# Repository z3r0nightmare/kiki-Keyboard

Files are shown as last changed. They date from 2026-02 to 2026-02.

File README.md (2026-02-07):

# Kiki v1 ⌨️

Kiki v1 is a modernized, high-performance split mechanical keyboard. This design is inspired by the **Corne v4.1 (Cherry Version)** but optimized for the **RP2040** processor. It features integrated MCU support, dual rotary encoders per side, and native **Vial** compatibility for real-time configuration.

---

## 📂 Repository Contents
* **/Hardware**: Gerber files, PCB designs, and BOM (Bill of Materials). Optimized for **NextPCB** assembly.
* **/Firmware**: Compiled `.uf2` files and QMK/Vial source code.
* **/Case**: STL files for 3D printing and CAD models for custom enclosures.

---

## 🛠 Hardware Build & Assembly
This PCB integrates the Raspberry Pi RP2040 directly onto the board, eliminating the need for separate Pro Micro controllers.

### 1. PCB Manufacturing
The files in the `/Hardware` folder are optimized for the **NextPCB** workflow. By using their assembly service with the provided **BOM** and **CPL** files, you can receive your boards with all SMD components (MCU, diodes, resistors) pre-soldered.

### 2. Rotary Encoders
The Kiki v1 supports dual encoders per side for maximum control. Note that firmware updates are ongoing to further optimize pin assignments; always ensure you are flashing the latest `.uf2` from the `/Firmware` folder to keep your hardware features fully active.

---

## 🚀 Software & Customization

### 1. Vial Support (Real-time Edits)
The Kiki v1 is **Vial-ready**, allowing you to change your layout, RGB effects, and encoder behavior without ever touching a line of code.
* **Download**: [vial.today](https://get.vial.today/)
* **Usage**: Plug in your keyboard, open the Vial app, and start remapping.
* **Reset**: If the layout visuals appear incorrectly in the app, navigate to `Security -> Reset to Factory Defaults` in the Vial menu to refresh the coordinate map.

### 2. Layout Options
The firmware supports multiple physical configurations:
* **3x6_3**: Standard 6-column experience.
* **3x5_3**: Compact 5-column layout for minimal finger travel.

### 3. OLED & Bongo Cat
The integrated OLED displays feature a reactive **Bongo Cat** animation. The cat's typing speed scales with your WPM (Words Per Minute), and the screen also displays your current layer and last key pressed.

---

## ⚡ How to Flash
1. Hold the **BOOT** button on the PCB while plugging in the USB-C cable.
2. A drive named `RPI-RP2` will appear on your computer.
3. Drag and drop the provided `.uf2` file onto that drive.
4. The keyboard will automatically reboot and be ready to use.

---

## 🎨 Credits & Inspiration
* **Base Inspiration**: Inspired by the **Corne (Crkbd) v4.1 Cherry** by foostan.
* **Firmware Framework**: Powered by [QMK Firmware](https://qmk.fm/) and [Vial](https://get.vial.today/).
* **Optimizations**: Custom RP2040 pinout integration and dual-encoder support.

---

## 📜 License
Open-source for personal use. If you build a Kiki v1 or feature it in a project, please link back to this repository!

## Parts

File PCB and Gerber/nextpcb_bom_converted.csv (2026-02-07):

Designator | Qty | Manufacturer | MPN | Package | Description
Y1,rY1 | 2 | EPSON | Q22FA23V00418 | SMD3225-4P | 12MHz Crystal 18pF
C1,C2,rC1,rC2 | 4 | FH | 0402CG270J500NT | 0402 | 27pF C0G 0402 Capacitor
R4,R5,rR4,rR5 | 4 | FOJAN | FRC0402F27R0TS | 0402 | 27Ω 0402 Resistor (or similar)
EXSW1,EXSW2,SW1,SW10,SW11,SW12,SW13,SW14,SW15,SW16,SW17,SW18,SW19,SW2,SW20,SW21,SW3,SW4,SW5,SW6,SW7,SW8,SW9,rEXSW1,rEXSW2,rSW1,rSW10,rSW11,rSW12,rSW13,rSW14,rSW15,rSW16,rSW17,rSW18,rSW19,rSW2,rSW20,rSW21,rSW3,rSW4,rSW5,rSW6,rSW7,rSW8,rSW9 | 46 | Kailh | CPG151101S11-16 | Pushbutton | Kailh Pushbutton Switch
J2,rJ2 | 2 | Korean Hroparts Elec | PJ-399B-6A | Through Hole | 3.5mm Headphone Jack
J1,rJ1 | 2 | Korean Hroparts Elec | TYPE-C-31-M-13C | SMD | USB Type-C Connector 16POS
EXLED1,EXLED2,LED1,LED10,LED11,LED12,LED13,LED14,LED15,LED16,LED17,LED18,LED19,LED2,LED20,LED21,LED3,LED4,LED5,LED6,LED7,LED8,LED9,rEXLED1,rEXLED2,rLED1,rLED10,rLED11,rLED12,rLED13,rLED14,rLED15,rLED16,rLED17,rLED18,rLED19,rLED2,rLED20,rLED21,rLED3,rLED4,rLED5,rLED6,rLED7,rLED8,rLED9 | 46 | OPSCO Optoelectronics | SK6812MINI-E | SMD | Addressable LED SK6812 MINI
U1,rU1 | 2 | Raspberry Pi | RP2040 | QFN | RP2040 MCU
C16,C5,C8,rC16,rC5,rC8 | 6 | Samsung Electro-Mechanics | CL05A105KA5NQNC | 0402 | 1uF 25V X5R 0402
C11,C6,rC11,rC6 | 4 | Samsung Electro-Mechanics | CL05A106MQ5NUNC | 0402 | 10uF 6.3V X5R 0402
C10,C12,C13,C14,C15,C3,C4,C7,C9,rC10,rC12,rC13,rC14,rC15,rC3,rC4,rC7,rC9 | 18 | Samsung Electro-Mechanics | CL05B104KO5NNNC | 0402 | 100nF 16V X7R 0402
U3,rU3 | 2 | TI | TPD4E05U06DQAR | USON-10(1x2.5) | TVS Diode
R3,R6,rR3,rR6 | 4 | UNI-ROYAL | 0402WGF1001TCE | 0402 | 1kΩ 0402 Resistor ±1%
R7,R9,rR7,rR9 | 4 | UNI-ROYAL | 0402WGF1002TCE | 0402 | 10kΩ 0402 Resistor
R1,R2,rR1,rR2 | 4 | UNI-ROYAL | 0402WGF5101TCE | 0402 | 5.1kΩ 0402 Resistor
R8,rR8 | 2 | UNI-ROYAL | 0402WGF5601TCE | 0402 | 5.6kΩ 0402 Resistor
U4,rU4 | 2 | Winbond | W25Q128JVSIQ | SOIC-8-208mil | 128Mbit SPI Flash Memory
SMDSW1,SMDSW2,rSMDSW1,rSMDSW2 | 4 | XUNPU | TS-1088R-02026 | SMD 4x3mm | Tactile Switch
D1,rD1 | 2 | onsemi | 1N4148WT | SOD-523F | General Purpose Diode 75V
U2,rU2 | 2 | onsemi | NCP1117LPST33T3G | SOT-223 | LDO 3.3V
ZD1,rZD1 | 2 | onsemi | RB521S30T1G | SOD-523 | Schottky Diode 30V

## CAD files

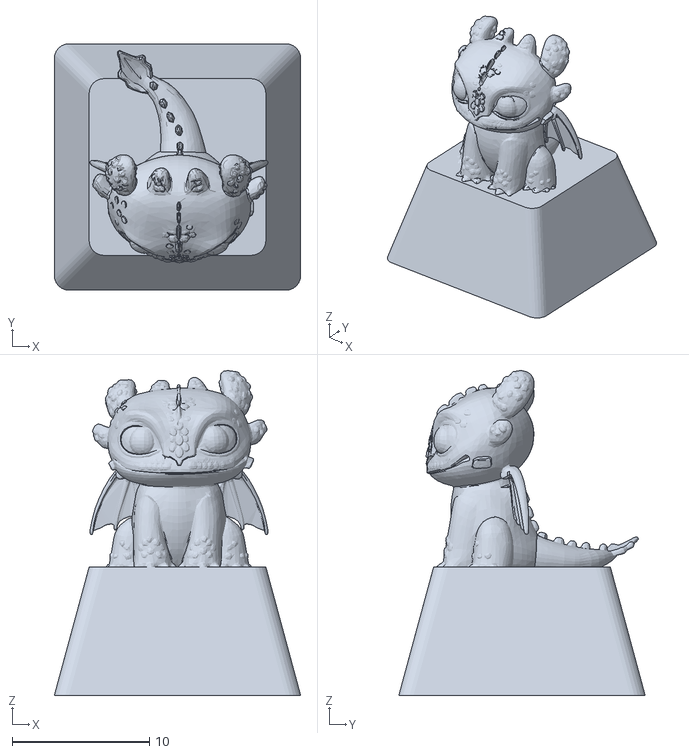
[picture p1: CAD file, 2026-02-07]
CAD Files/night fury keycap.stl.stl
18.0 x 18.0 x 23.7

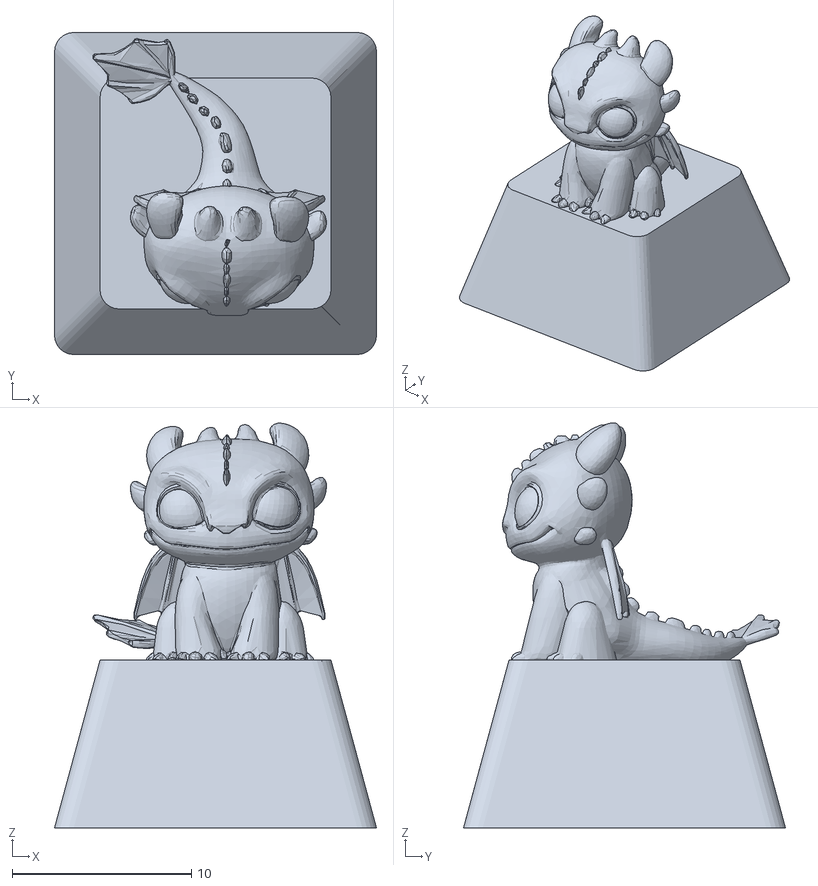
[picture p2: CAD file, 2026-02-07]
CAD Files/light fury keycap.stl(1).stl
18.0 x 18.0 x 22.6

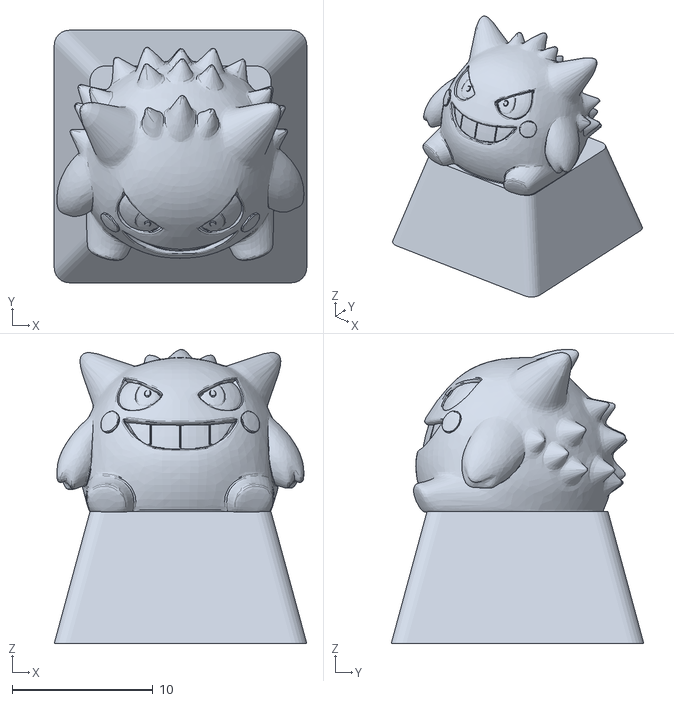
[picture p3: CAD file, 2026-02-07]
CAD Files/gengar keycap.stl(1).stl
18.0 x 18.0 x 20.9

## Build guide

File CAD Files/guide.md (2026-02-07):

# Kiki v1: 3D Printing & CAD Guide 🛠️

This folder contains the structural components for the Kiki v1. The design is optimized for the **Corne v4.1 Cherry** form factor but adapted for integrated RP2040 components.

## 📁 File Descriptions
* **`Case_Top.stl`**: The main bezel for the switch plate.
* **`Case_Bottom.stl`**: The base enclosure. Includes cutouts for the USB-C port and OLED.
* **`Kiki_v1_Full_Assembly.step`**: Use this CAD file if you want to modify the design in Fusion 360, Blender, or FreeCAD.

## 🖨️ Printing Recommendations
* **Material**: PLA for standard builds; PETG or ABS if you want more heat resistance.
* **Infill**: 20% or higher for a solid "thocky" sound.
* **Supports**: Required for the USB-C port opening and the OLED window.
* **Layer Height**: 0.2mm is standard, but 0.16mm will give the curves a smoother finish.

## 🛠️ Post-Processing
1. Remove support material carefully around the MCU area.
2. Use M2 or M3 screws (check your specific PCB holes) to secure the PCB to the bottom case.

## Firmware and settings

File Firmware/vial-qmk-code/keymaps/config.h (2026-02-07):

#pragma once

#define VIAL_KEYBOARD_UID {0x3B, 0x6B, 0xA0, 0x29, 0x80, 0x56, 0xED, 0xD1, 0x01, 0x02, 0x03, 0x04, 0x05, 0x06, 0x07, 0x08}
#define VIAL_UNLOCK_COMBO_ROWS {0, 0}
#define VIAL_UNLOCK_COMBO_COLS {0, 1}

#define MASTER_LEFT

/* RGB Matrix Configuration - Per-Key Patterns */
#undef RGB_DI_PIN
#define RGB_DI_PIN GP10 
#undef DRIVER_LED_TOTAL
#define DRIVER_LED_TOTAL 46
#undef RGB_MATRIX_MAXIMUM_BRIGHTNESS
#define RGB_MATRIX_MAXIMUM_BRIGHTNESS 150

#ifdef RGB_MATRIX_ENABLE
    #define RGB_MATRIX_KEYPRESSES
    #define RGB_MATRIX_FRAMEBUFFER_EFFECTS
    #define RGB_MATRIX_EFFECT_SPLASH
    #define RGB_MATRIX_EFFECT_SOLID_REACTIVE_WIDE
    #define RGB_MATRIX_EFFECT_RAINBOW_MOVING_CHEVRON
#endif

/* Encoder Setup - 2 on the RIGHT Side Only */
#undef NUM_ENCODERS
#define NUM_ENCODERS 2

#undef ENCODER_A_PINS
#undef ENCODER_B_PINS
#define ENCODER_A_PINS { }
#define ENCODER_B_PINS { }

#undef ENCODER_A_PINS_RIGHT
#undef ENCODER_B_PINS_RIGHT
#define ENCODER_A_PINS_RIGHT { GP24, GP6 }
#define ENCODER_B_PINS_RIGHT { GP7, GP7 }

#define ENCODER_RESOLUTION 4

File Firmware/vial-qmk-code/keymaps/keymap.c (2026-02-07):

#include QMK_KEYBOARD_H

// --- Bongo Cat Animation Logic ---
#define IDLE_SPEED 10
#define TAP_SPEED 1
// --- Bongo Cat Animation Logic (Updated to match your oled.c) ---
#define ANIM_FRAME_DURATION 50 
#define ANIM_SIZE 512
#define IDLE_FRAMES 5
#define TAP_FRAMES 2
void set_keylog(uint16_t keycode, keyrecord_t *record);
bool process_record_user(uint16_t keycode, keyrecord_t *record) {
    if (record->event.pressed) {
        set_keylog(keycode, record); // This sends the key to the OLED code
    }
    return true;
}
const uint16_t PROGMEM keymaps[][MATRIX_ROWS][MATRIX_COLS] = {
    [0] = LAYOUT_split_3x6_3(
        KC_ESC,  KC_Q,    KC_W,    KC_E,    KC_R,    KC_T,                      KC_Y,    KC_U,    KC_I,    KC_O,    KC_P,    KC_BSPC,
        KC_TAB,  KC_A,    KC_S,    KC_D,    KC_F,    KC_G,                      KC_H,    KC_J,    KC_K,    KC_L,    KC_SCLN, KC_QUOT,
        KC_LSFT, KC_Z,    KC_X,    KC_C,    KC_V,    KC_B,                      KC_N,    KC_M,    KC_COMM, KC_DOT,  KC_SLSH, KC_ENT,
                                            KC_LCTL, MO(1),   KC_SPC,  KC_ENT,  MO(2),   KC_RALT
    ),
    [1] = LAYOUT_split_3x6_3(
        KC_GRV,  KC_1,    KC_2,    KC_3,    KC_4,    KC_5,                      KC_6,    KC_7,    KC_8,    KC_9,    KC_0,    KC_DEL,
        KC_TRNS, KC_TRNS, KC_TRNS, KC_TRNS, KC_TRNS, KC_TRNS,                 KC_LEFT, KC_DOWN, KC_UP,   KC_RGHT, KC_TRNS, KC_TRNS,
        KC_TRNS, KC_TRNS, KC_TRNS, KC_TRNS, KC_TRNS, KC_TRNS,                 KC_TRNS, KC_TRNS, KC_TRNS, KC_TRNS, KC_TRNS, KC_TRNS,
                                            KC_TRNS, KC_TRNS, KC_TRNS, KC_TRNS, MO(3),   KC_TRNS
    ),
    [2] = LAYOUT_split_3x6_3(
        KC_TRNS, KC_EXLM, KC_AT,   KC_HASH, KC_DLR,  KC_PERC,                   KC_CIRC, KC_AMPR, KC_ASTR, KC_LPRN, KC_RPRN, KC_TRNS,
        KC_TRNS, KC_TRNS, KC_TRNS, KC_TRNS, KC_TRNS, KC_TRNS,                 KC_MINS, KC_EQL,  KC_LBRC, KC_RBRC, KC_BSLS, KC_GRV,
        KC_TRNS, KC_TRNS, KC_TRNS, KC_TRNS, KC_TRNS, KC_TRNS,                 KC_UNDS, KC_PLUS, KC_LCBR, KC_RCBR, KC_PIPE, KC_TILD,
                                            KC_TRNS, MO(3),   KC_TRNS, KC_TRNS, KC_TRNS, KC_TRNS
    ),
    [3] = LAYOUT_split_3x6_3(
        KC_TRNS, KC_F1,   KC_F2,   KC_F3,   KC_F4,   KC_F5,                     KC_F6,   KC_F7,   KC_F8,   KC_F9,   KC_F10,  KC_F11,
        KC_TRNS, KC_TRNS, KC_TRNS, KC_TRNS, KC_TRNS, KC_TRNS,                 KC_TRNS, KC_TRNS, KC_TRNS, KC_TRNS, KC_F12,  KC_TRNS,
        KC_TRNS, KC_TRNS, KC_TRNS, KC_TRNS, KC_TRNS, KC_TRNS,                 KC_TRNS, KC_TRNS, KC_TRNS, KC_TRNS, KC_TRNS, KC_TRNS,
                                            KC_TRNS, KC_TRNS, KC_TRNS, KC_TRNS, KC_TRNS, KC_TRNS
    )
};


#ifdef ENCODER_MAP_ENABLE
const uint16_t PROGMEM encoder_map[][NUM_ENCODERS][NUM_DIRECTIONS] = {
    [0] = { ENCODER_CCW_CW(KC_VOLD, KC_VOLU), ENCODER_CCW_CW(KC_BRID, KC_BRIU) },
    [1] = { ENCODER_CCW_CW(KC_TRNS, KC_TRNS), ENCODER_CCW_CW(KC_TRNS, KC_TRNS) },
    [2] = { ENCODER_CCW_CW(KC_TRNS, KC_TRNS), ENCODER_CCW_CW(KC_TRNS, KC_TRNS) },
    [3] = { ENCODER_CCW_CW(KC_TRNS, KC_TRNS), ENCODER_CCW_CW(KC_TRNS, KC_TRNS) }
};
#endif

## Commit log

2026-02-07 Add Vial configuration for Crkbd 3x6 with Encoders
2026-02-07 Create guide.md for Kiki v1 3D printing and CAD
    Added a comprehensive guide for Kiki v1 3D printing and CAD.
2026-02-07 Adding Keycaps stls
    [gengar keycap.stl(1).stl, light fury keycap.stl(1).stl, night fury keycap.stl.stl]
2026-02-07 adding pcb guide
2026-02-07 gerber added
2026-02-07 BOM updated
    [nextpcb_bom_converted.csv]
